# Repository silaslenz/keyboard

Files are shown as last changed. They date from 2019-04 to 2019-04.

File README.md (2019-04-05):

# Keyboard

A split keyboard. Current layout: http://www.keyboard-layout-editor.com/#/gists/ab432df886ce0812838ef99259da4404

See [keyboards/sisplit](https://github.com/silaslenz/qmk_firmware/tree/1df4aca1ef950e725eda1459dbb818511b1fa2ed/keyboards/sisplit) for firmware and run `make sisplit/rev2:default:avrdude` to install.

## Targets
* Split keyboard
* 3D-printable except for electronics/switches.
* Roughly 85%-size in Ergodox/Microsoft sculpt-style (F-row, thumb cluster and arrow keys but no numpad).
* Tenting
* Running QMK

## Component list
* 88x [Gateron Brown](https://www.banggood.com/10PCS-3-Pin-Mechanical-Keyboard-Switch-Brown-Switch-for-Gateron-Keyboard-Replacement-p-1119473.html): ~$30
* 88x [1N4148 Diodes](https://www.banggood.com/100pcs-1N4148-Switching-Diode-Kit-DIY-Electronic-Component-Set-Straight-Pin-DO-35-p-1182125.html): ~$2
* 2x [TRRS Jack Module](https://www.banggood.com/3pcs-3_5mm-Plug-Jack-Stereo-TRRS-Headset-Audio-Socket-Breakout-Board-Extension-Module-p-1405159.html): ~$4
* 2x [Arduino pro micro](https://www.banggood.com/Pro-Micro-5V-16M-Mini-Leonardo-Microcontroller-Development-Board-For-Arduino-p-1077675.html): ~$8
* 1x TRRS Cable: ~$2
* 3D printed case: ~$7 for materials
* 3D printed flat keycaps ~$2
* Wires

Total: ~$55

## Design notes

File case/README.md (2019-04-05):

# Case

`jsonPositions.py` from https://github.com/Lenbok/scad-redox-case

Case design was done using OnShape: https://cad.onshape.com/documents/dd3a40a5ed605083cfbf3990/w/82b7bddab61a2b6cbcf17e8c/e/b49ff9ea8062e97cecc28f36

Comment out one of the `const key_layout` arrays in the feature studio to switch between left and right parts.

## Stuff to print
* One each of `left-bottom.stl`, `left-top.stl`, `right-bottom.stl`, `right-top.stl`.
* 12 of `tent-nut.stl`, two for each of the bolts.
* 2 of `tent-bolt-short.stl` for the thumb cluster tenting position.
* 4 of `tent-bolt.stl` for the other tenting positions.

# Keycaps
Keycaps where also designed using onshape: https://cad.onshape.com/documents/d67b44172e642988c616e11f/w/3eda0524007876da50b065d1/e/4574dfdf04ae35f8a288d57f

Modify `width` and/or `height` variables for special keys, move down rollback bar and modify `Lettering sketch` to add text or other shapes.

## How to print
* First print the letter parts (one layer). Don't forget to rotate by 180 degrees around the Y axis.
* Print the keycaps on top without removing the letters from the bed. Also print bottom up by rotating 180 degrees around the Y axis and position on top of the letters.

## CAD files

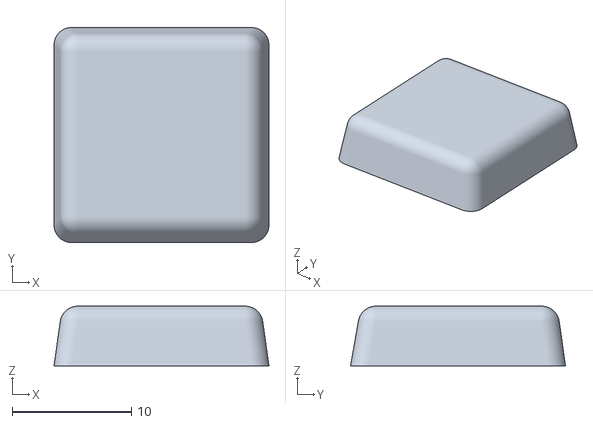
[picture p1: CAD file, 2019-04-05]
case/stls/standard-key-no-text.stl
18.0 x 18.0 x 5.00

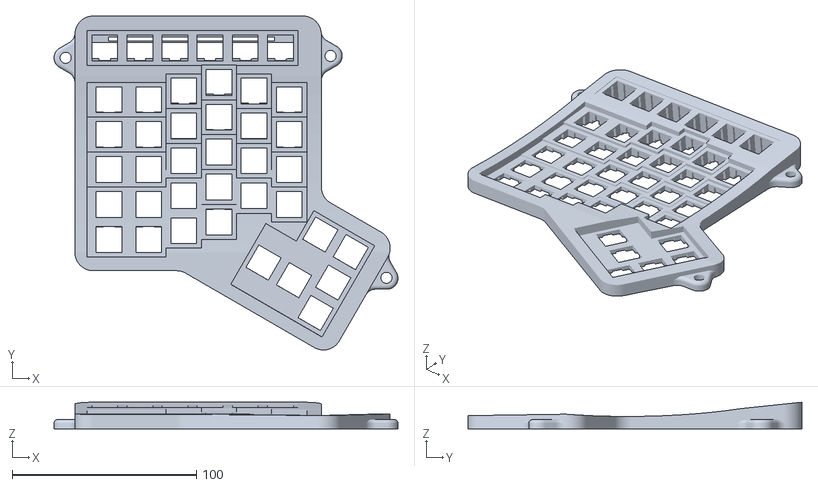
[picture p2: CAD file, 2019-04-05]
case/stls/left-top.stl
186.5 x 181.1 x 14.4

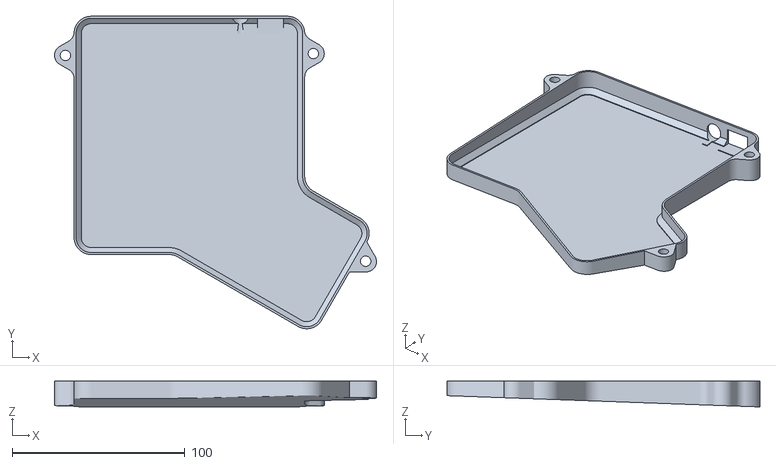
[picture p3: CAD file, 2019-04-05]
case/stls/left-bottom.stl
186.5 x 181.1 x 15.0

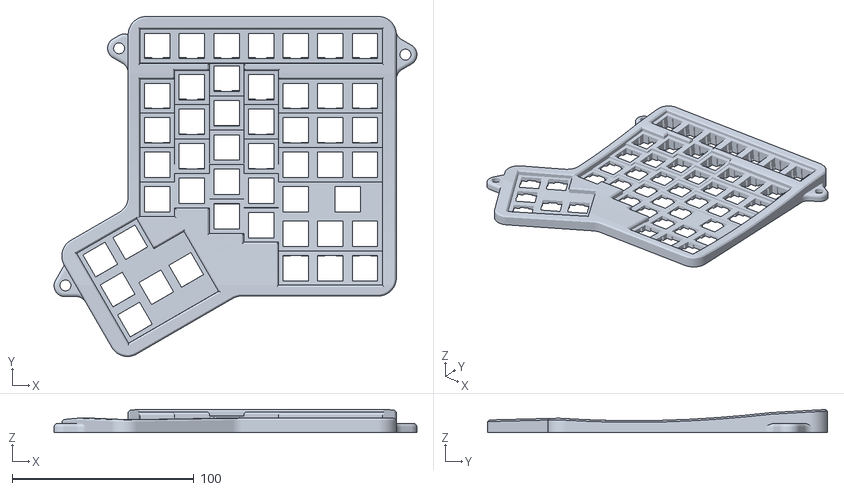
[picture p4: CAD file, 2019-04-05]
case/stls/right-top.stl
199.7 x 187.1 x 12.7

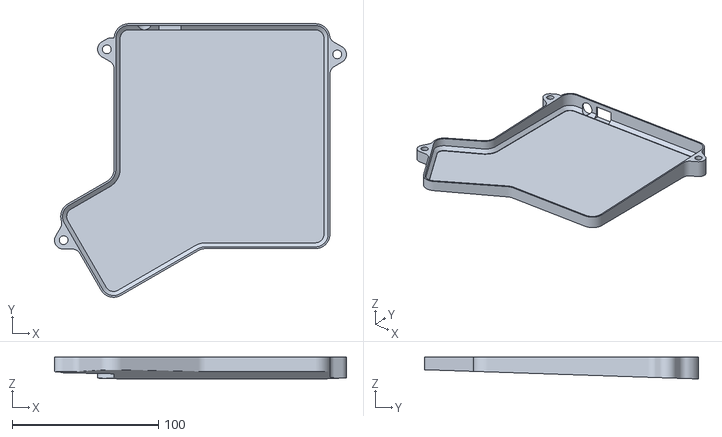
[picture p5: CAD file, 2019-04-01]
case/stls/right-bottom.stl
199.7 x 187.1 x 15.0

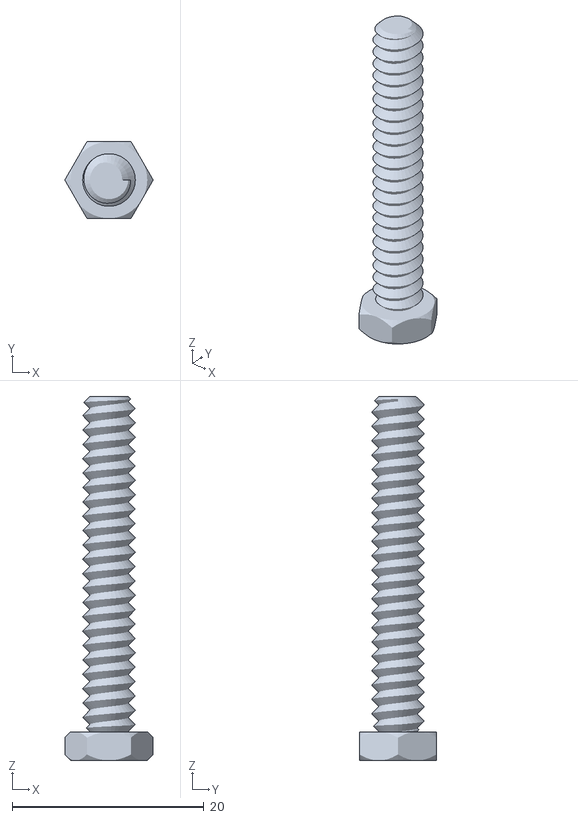
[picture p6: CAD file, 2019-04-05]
case/stls/tent-bolt-short.stl
9.24 x 8.00 x 38.0

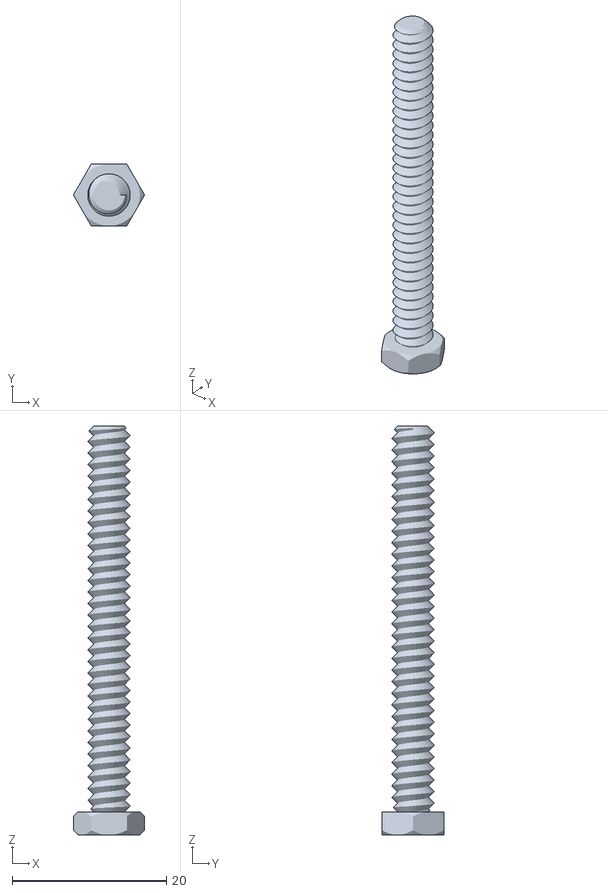
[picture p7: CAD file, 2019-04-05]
case/stls/tent-bolt.stl
9.24 x 8.00 x 53.0

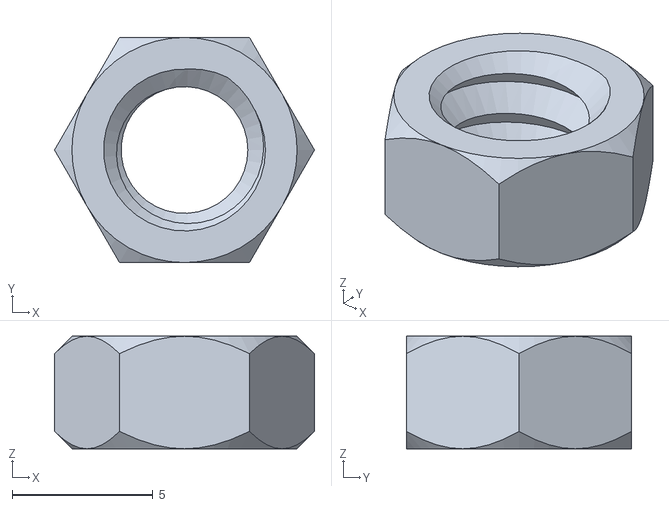
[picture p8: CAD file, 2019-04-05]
case/stls/tent-nut.stl
9.24 x 8.00 x 4.00

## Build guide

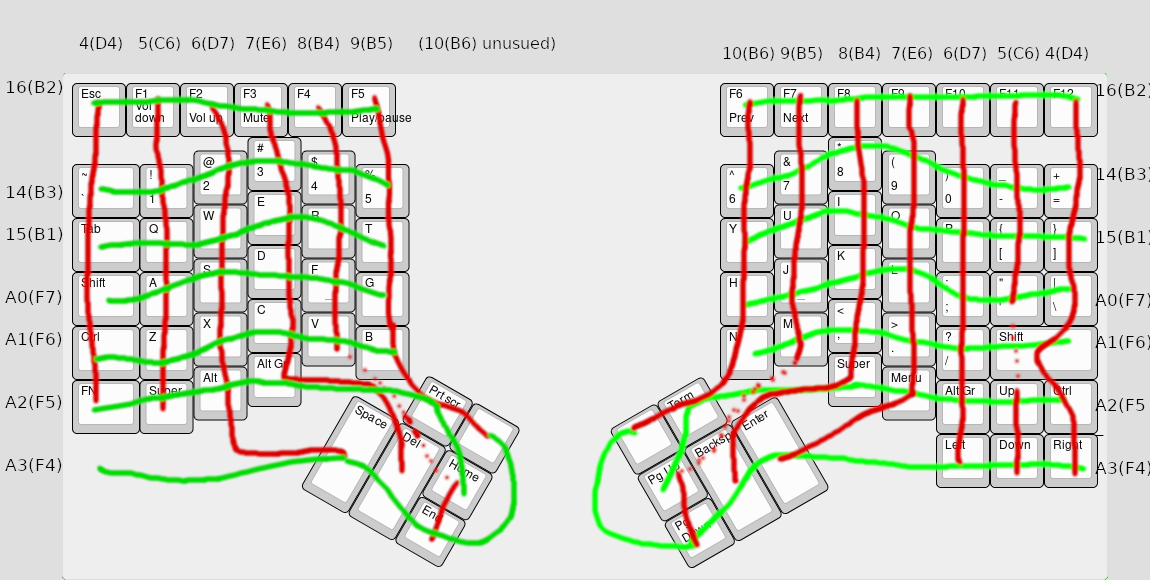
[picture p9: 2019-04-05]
wiring.png

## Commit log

2019-03-09 Add case files
    [bezier.scad, keyboard-case.scad, main.scad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]
2019-03-09 First simple case design
    [main.scad]
2019-03-10 Switch to staggered ortholinear layout
    [main.scad, my_keyboard.scad]
2019-03-11 Slightly more compact layout with easier to reach to important keys (L_CTRL, L_SHIFT)
    [main.scad, my_keyboard.scad]
2019-04-01 Add first printed components
    [left-bottom.stl, left-top.stl, right-bottom.stl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]
2019-04-01 Add keycap stl
    [keycap-no-text.stl]
2019-04-05 Add image of wiring
2019-04-05 Remove no longer used SCAD files
    [keyboard-case.scad, main.scad, my_keyboard.scad]
2019-04-05 Lenbok utils no longer needed
    [bezier.scad, utils.scad]
2019-04-05 Update main stls to final version
    [left-bottom.stl, left-top.stl, right-top.stl]
2019-04-05 Add tenting stls
    [tent-bolt-short.stl, tent-bolt.stl, tent-nut.stl]
2019-04-05 Update case README with links and instructions
2019-04-05 Update to final keycap design
    [keycap-no-text.stl, standard-key-no-text.stl]
